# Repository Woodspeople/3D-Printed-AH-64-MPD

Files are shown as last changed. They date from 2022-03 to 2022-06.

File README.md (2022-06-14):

Welcome to the AH-64 Printed MPD project.
-
Image of construted MPDs Image of CAD model

The goal of this project was to design a hardware setup for the AH-64, allowing users to chose their own electronics to connect it to.

Here is a summary of the files in this repository:

**Arduino_IDE_sketches (folder)**  
This folder contains my Arduino/Teensyduino sketches for USB HID input.

**odt_files (folder)**  
This folder contains the original source files for the PDFs in the repository.
The .odt file for the build guide is quite large (135MB) so these files are stored with Git Large File Storage. If you want to download them you can do so by previewing them in the repository and clicking download there.

**Stls (folder)**  
This folder contains binary .stl files for all the required 3D printed parts.

**ah-64_electronics_guide.pdf**  
This brief guide summarizes my electronics setups.

**ah-64_mpd_BoM.pdf**  
This document contains a full list of materials required to complete the frame.

**ah-64_mpd_build_guide_pictures_rc1.pdf**  
This guide contains a full set of step by step instructions to build the frame.

**ah-64d mpd v15.f3z**  
This is an export of the latest version (at time of writing) of the cad files.

**ah-64d mpd v15.step**  
Alternate export for any programs that might not support .f3z files.

Check out the build guide or Bill of materials for more information.
-
Made in Autodesk Fusion 360 (Educational License)

3D Printed AH-64 MPD project © 2022 by Elliot Fernhout is licensed under CC BY-NC 4.0. To view a copy of this license, visit http://creativecommons.org/licenses/by-nc/4.0/

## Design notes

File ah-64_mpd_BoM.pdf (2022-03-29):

AH-64 MPD BoM
ITEM NO. | QTY. | PART NAME | DESCRIPTION | LENGTH
1 | 1 | Front frame | 3D printed | -
2 | 1 | Middle frame | ^ | -
3 | 1 | Back cover | | -
4 | 24 | square button | | -
5 | 7 | Rectangular button | | -
6 | 31 | Tactile Switch | 5 x 6 x 6mm Switch | -
7 | 2 | Potentiometer | B10K suggested | -
8 | 1 | 3 position switch | SR1712F-0103 | -
9 | 6 | Upper OSB signal wire | 26AWG stranded (white) | 390mm + length of harness
10 | 2 | Potentiometer signal wire | 26AWG stranded (yellow) | 390mm + length of harness
11 | 2 | 3 pos. switch signal wire | 26AWG stranded (blue) | 390mm + length of harness
12 | 1 | Potentiometer 5v wire | 26AWG stranded (red) | 390mm + length of harness
13 | 17 | Middle OSB signal wire | 26AWG stranded (white) | 270mm + length of harness
14 | 8 | Lower OSB signal wire | 26AWG stranded (white) | 120mm + length of harness
15 | 1 | Ground connector wire | 26AWG stranded (black) | 30mm + length of harness
16 | 37 | OSB/switch ground lead | 26AWG stranded (black) | 65mm
17 | 2 | Potentiometer signal lead | 26AWG stranded (yellow) | 65mm
18 | 2 | 3 pos. switch signal lead | 26AWG stranded (blue) | 65mm
19 | 3 | Potentiometer 5v lead | 26AWG stranded (red) | 65mm
20 | 1 | Main ground conductor | 22AWG solid core (bare) | 800mm
21 | 46 | Male wire connector | DuPont (0.1in pitch) | -
22 | 9 | Female wire connector | DuPont (0.1in pitch) | -
22 | 8 | Frame bolt | M3x25 (any head type) | 25mm
23 | N/A | Cable management supplies | Cable ties or lacing suggested

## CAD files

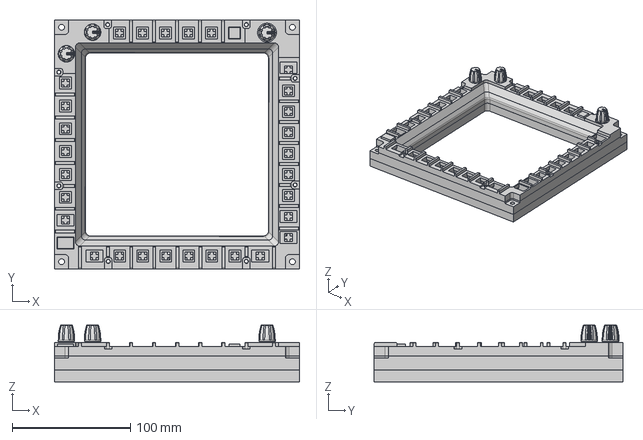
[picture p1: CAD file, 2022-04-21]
ah-64d mfd v18.step
207.5 x 210.5 x 48.0 mm
ah-64 knob v4 x 3

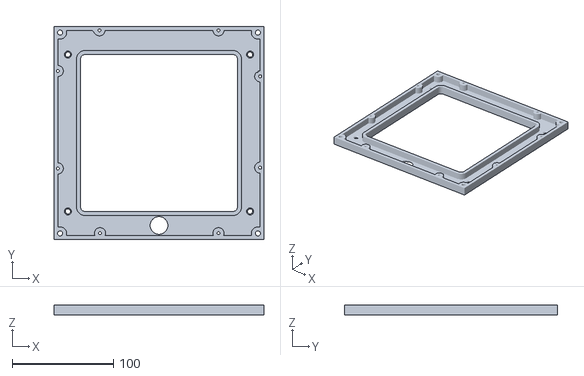
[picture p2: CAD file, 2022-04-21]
Stls/back_cover.stl
207.5 x 210.5 x 10.0

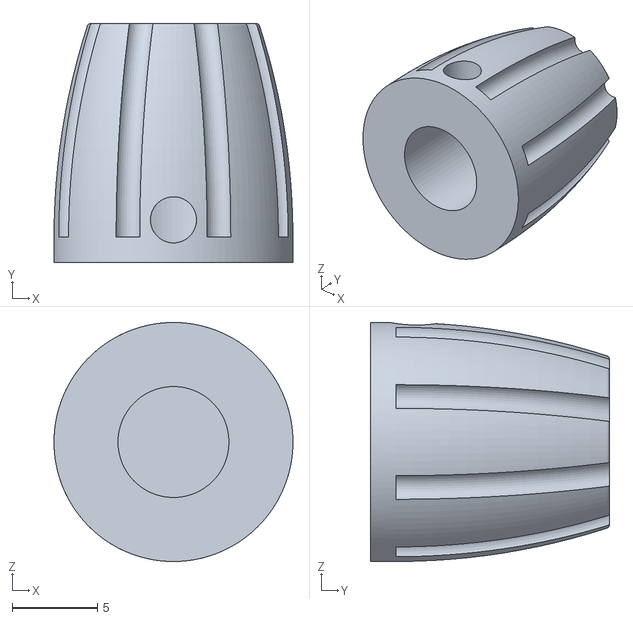
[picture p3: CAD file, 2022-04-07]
Stls/Knob/knob_no_inserts.stl
14.0 x 14.0 x 14.0

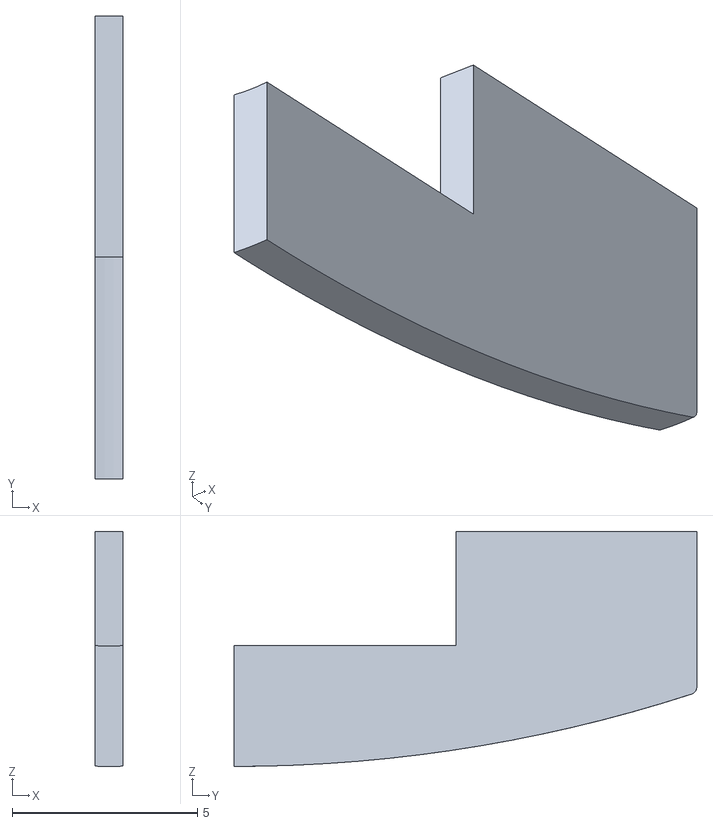
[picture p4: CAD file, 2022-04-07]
Stls/Knob/white_insert.stl
0.75 x 12.5 x 6.35

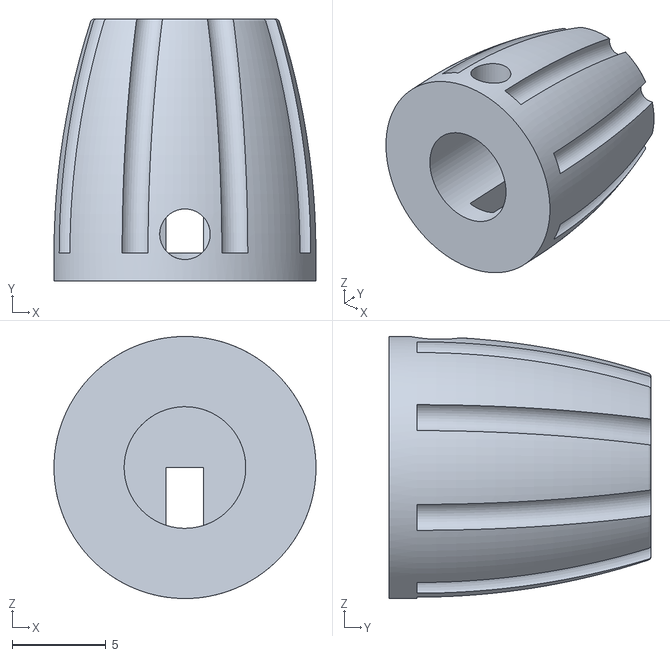
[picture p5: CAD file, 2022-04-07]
Stls/Knob/Knob_with_insert.stl
14.0 x 14.0 x 14.0

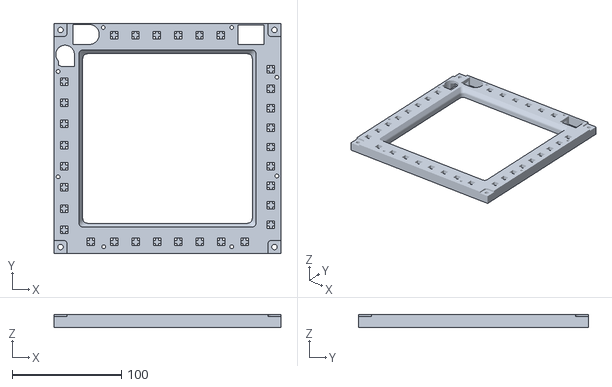
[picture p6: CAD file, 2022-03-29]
Stls/middle_frame.stl
207.5 x 210.5 x 12.0

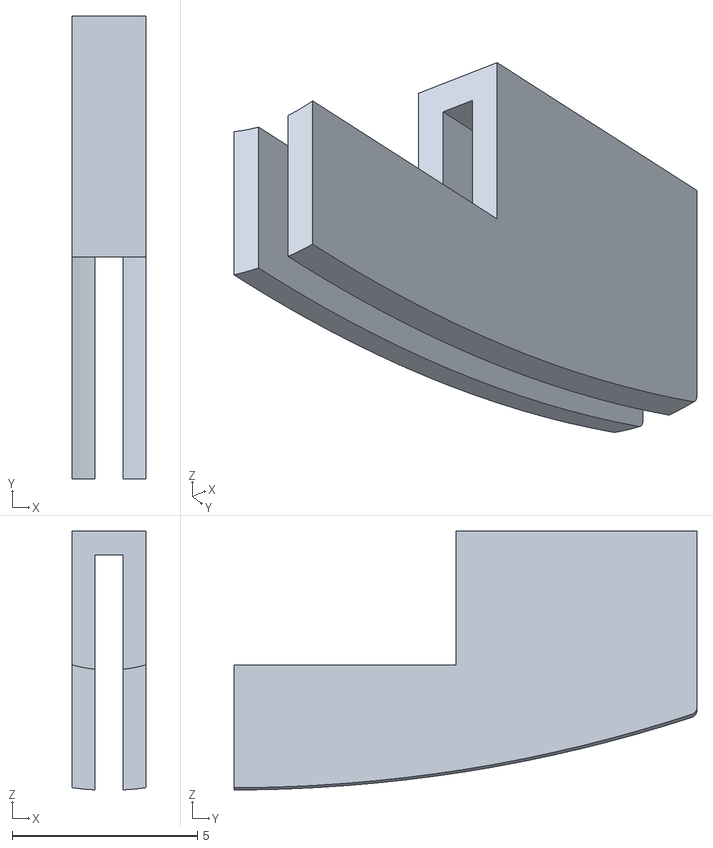
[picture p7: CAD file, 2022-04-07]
Stls/Knob/black_insert.stl
2.00 x 12.5 x 6.99

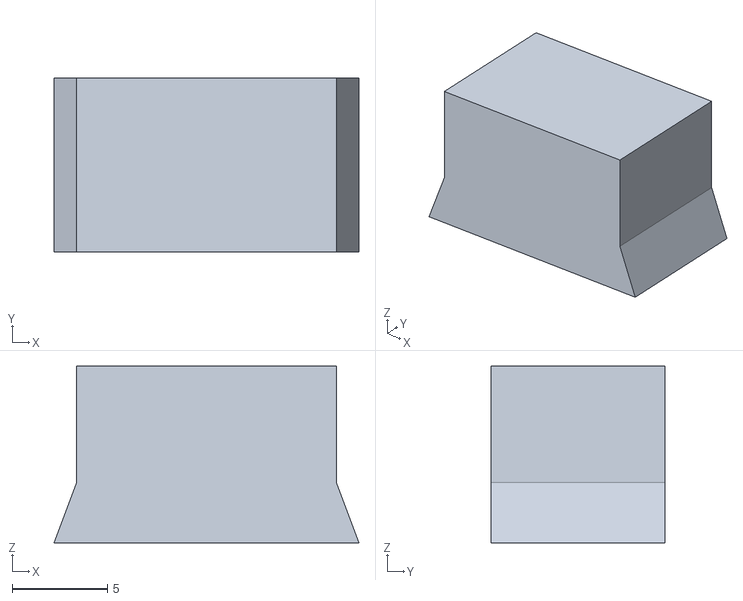
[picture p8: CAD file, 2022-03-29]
Stls/rectangular_button_(x7).stl
16.0 x 9.10 x 9.25

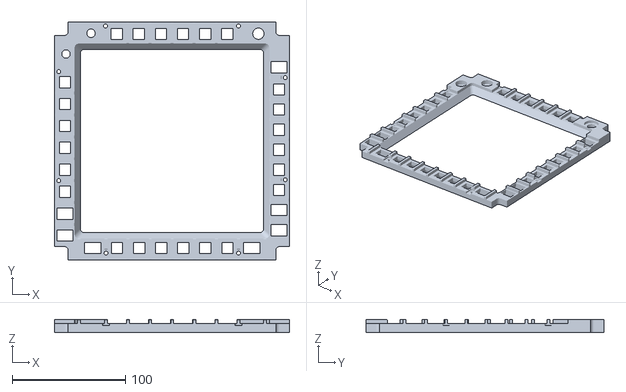
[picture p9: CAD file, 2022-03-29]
Stls/front_frame.stl
207.5 x 210.5 x 11.5

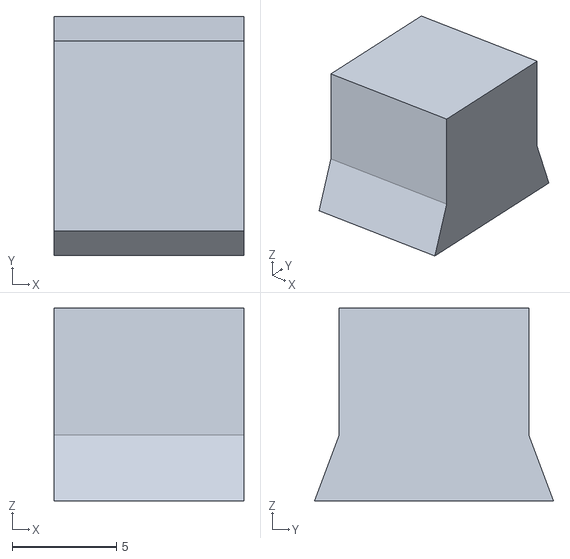
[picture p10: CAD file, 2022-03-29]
Stls/square_button_(x24).stl
9.10 x 11.5 x 9.25

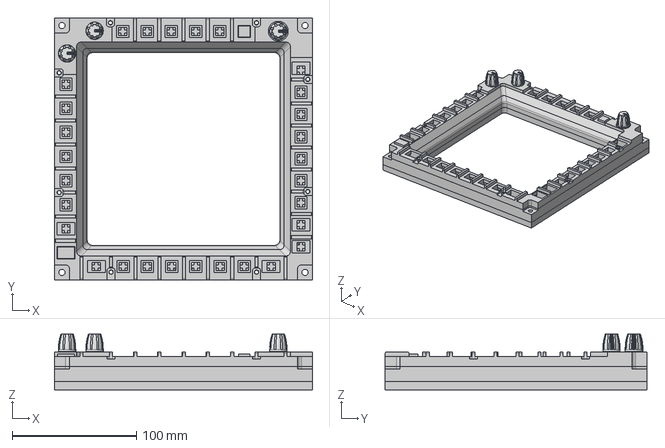
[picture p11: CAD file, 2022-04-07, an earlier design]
ah-64d mfd v17.step
207.5 x 210.5 x 45.0 mm
ah-64 knob v4 x 3

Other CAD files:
Stls/knob_no_inserts.stl
ah-64d mfd v18.f3z

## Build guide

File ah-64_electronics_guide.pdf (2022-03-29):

Electronics guide

This is a brief overview of my electronics setup for the ah-64 MPD project.

For both MPDs I used a heavy object and a multimeter to determine which lead corresponded to what button.
Once I knew which pins where connected to what, I plugged them into the pin headers on my boards in order.

For the left MPD, I chose an Arduino Mega knockoff board as the controller. The main chip on the Arduino Mega does not natively support USB HID (at least in the configuration that is on the board) so a workaround is required.

I used Nico Hood’s wonderful Hoodloader2 library to solve this problem. (https://github.com/NicoHood/HoodLoader2)

With Hoodloader2, I am able to program a sketch onto both the smaller ATmega16U2 chip, and the larger ATmega2560 chip while still having an onboard programmer available to update the ATmega2560.

The ATmega2560 runs a sketch that polls the input and constructs serial data to send to the 16u2.

The ATmega16U2 runs a sketch containing a serial receiver that processes the serial data, and inputs it to a USB HID library that transmits the data to the computer.

The HID library is also written by Nico Hood. (https://github.com/NicoHood/HID)

For the right MPD, I did not have another Arduino Mega, so I chose to use a Teensy 3.6 instead. The Teensy 3.6 has native USB HID support so no workarounds are required.

I wrote a simple sketch to poll the inputs and send them to the computer using the Teensy native hid.

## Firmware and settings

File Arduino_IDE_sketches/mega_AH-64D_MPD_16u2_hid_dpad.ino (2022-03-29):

#include <HID-Project.h>
#include <HID-Settings.h>

union DATA_BUFFER_UNION
{
  uint64_t data = 0; 
  struct DATA_BUFFER_STRUCT
  {
    uint32_t buttonsState : 32;
    uint8_t switchState : 8;
    uint8_t unused : 8;
    uint8_t analogIn0 : 8;
    uint8_t analogIn1 : 8;
  }data_struct;
}dataUnion;


bool dataReady = false;

void setup() {
  Serial.begin(9600);
  Serial1.begin(960000);
  Gamepad.begin();
  delay(5000);
  pinMode(3,INPUT_PULLUP); //remove this
}

void loop() 
{
  //Serial.write("sending 0xA");
  Serial1.write("a");
  delay(5);
  //Serial.println(Serial1.available());
  if (Serial1.available() > 7)
  {
    while (Serial1.available() > 0)
    {
      dataUnion.data <<= 8;
      dataUnion.data |= Serial1.read();
    }
    dataReady = true;

   //print serial monitor.
  /*Serial.print("data received. > ");
  uint64_t pipe = dataUnion.data;
  uint32_t *p = (uint32_t *)&pipe;
  Serial.print(p[1],BIN);
  Serial.print(" | ");
  Serial.println(p[0],BIN); */
   //back to the main code.
  
  } 
  if (dataReady)
  {
    Gamepad.buttons(dataUnion.data_struct.buttonsState);
    Gamepad.xAxis(dataUnion.data_struct.analogIn0);
    Gamepad.yAxis(dataUnion.data_struct.analogIn1);
    Gamepad.dPad1(dataUnion.data_struct.switchState + 1);
    Gamepad.write();
    dataReady = false;
  }
  delay(15);
}

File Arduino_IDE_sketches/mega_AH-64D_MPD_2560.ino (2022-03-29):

const uint8_t mapSize = 32;
const uint8_t pinMap[mapSize] = {
  53,52,51,50, 49,48,47,46,
  45,44,43,42, 41,40,39,38,
  37,36,35,34, 33,32,31,30,
  29,28,27,26, 25,24,23,22//end

};

uint8_t inputBuffer[8];


void setup() 
{ 
  Serial.begin(960000);
  for (uint8_t i = 0; i < 32; i++)
  {
    pinMode(pinMap[i],INPUT_PULLUP); 
  }
  pinMode(2,INPUT_PULLUP);
  pinMode(3,INPUT_PULLUP);
}

void loop() 
{
  // Read button values //
  uint8_t i = 0;
  for (uint8_t j = 4; j < 8; j++)
  {
    for (uint8_t k = 0; k < 8; k++)
    {
      inputBuffer[j] = inputBuffer[j] << 1;
      if (!digitalRead(pinMap[i]))
      {
        inputBuffer[j] = inputBuffer[j] | 1;
      }
      i++; 
    }
  }
  
  // Read toggle switch and encode? //
  if (!digitalRead(2))
  {
    inputBuffer[3] = 1;
  }
  else if (!digitalRead(3))
  {
    inputBuffer[3] = 2;
  }
  else
  {
    inputBuffer[3] = 0;
  }
  // Read potentiometers //

  inputBuffer[0] = analogRead(A0) >> 2;
  inputBuffer[1] = analogRead(A1) >> 2;

  
  //Serial.write(Serial.available());
  if (Serial.available())
    {
      Serial.read();
      
      for (uint8_t i = 0; i < 8; i++)
      {
        Serial.write(inputBuffer[i]);
        //Serial.write(0xBB);
      }
    }
}

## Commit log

2022-03-29 Fix directory naming structure
    [AH_64_mpd_BoM.ods]
2022-04-07 Add knobs for potentiometers
    Includes updated .f3z, updated .stp, and stl files for the knobs.
    [Knob_with_insert.stl, ah-64d mfd v16.f3z, ah-64d mfd v17.step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]
2022-04-21 Increase back cover depth by 3mm
    Wiring does not fit well in current version, increased tolerances allow for easier assembly.
    [ah-64d mfd v16.f3z, ah-64d mfd v18.f3z, ah-64d mfd v18.step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]
